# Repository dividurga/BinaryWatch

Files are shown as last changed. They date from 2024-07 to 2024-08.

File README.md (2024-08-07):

# Binary Watch Project

Welcome to the Binary Watch project! This repository contains all the files related to the design and development of binary watches using STM32 and ATMega328p microcontrollers. A blog post detailing this can be found at [https://divija.info/](https://divija.info/2024/08/04/binary-display-watch/)

## Project Overview

The Binary Watch is designed to display the time in a "binary but base 10 format". This means each digit of the time in base 10 format is displayed in binary on an LED matrix.

For example, 17:15 is expressed on the LED matrix as:

<pre>
  0   0
  1 0 1
0 1 0 0
1 1 1 1
</pre>

where 1 = LED ON and 0 = LED OFF

## Repository Structure

### watch_STM32
This directory contains the design and firmware for the STM32-based binary watch.

### watch_ATMega328p
This directory contains the design for the ATMega328p-based binary watch.

The firmware from the STM32 version can be modified to work for this hardware. Use the arduino versions of all the libraries and an RTC library for the DS3231 RTC chip

### Setting the Time

- When the code is uploaded for the first time, the RTC time is set to the compile time.
- The current time is displayed on the LED matrix in binary format.
- Everytime you reset or change the battery, the time is set to midnight. This choice is purely aesthetic; I would prefer that my watch always resets to a defined time instead of a random compile time everytime setup() runs. This is achieved by storing a flag in the EEPROM.

## Contributing

Contributions are welcome! I'm still struggling with getting the external oscillator to work with my setup. I think the issue is with my choice of extenal capacitors - they should be 15pF instead of 1pF. The RTC section of the code works perfectly fine on an external Nucleo board, so I think it is a hardware issue. If you have any suggestions or improvements, please open an issue or submit a pull request.

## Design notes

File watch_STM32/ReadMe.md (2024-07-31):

## Directory Structure

- **EEPROMReset**: The firmware uses a flag stored in the EEPROM to see if the RTC needs to be reset. This file resets the flag. Flash this code before using flashing watchFirmwareSTM32.ino .
- **watchFirmwareSTM32.ino**: The main firmware file for the binary watch.
- **watch_STM32 v26.f3z**: Fusion 360 archive file containing the design of the watch, including PCB and 3D models.
- **ReadMe.md**: The current readme file.

### Prerequisites

- [STM32CubeIDE](https://www.st.com/en/development-tools/stm32cubeide.html) or [Arduino IDE](https://www.arduino.cc/en/software) (with STM32 support)
- [Fusion 360](https://www.autodesk.com/products/fusion-360/overview) for 3D modeling and PCB design
- [Arduino IDE](https://www.arduino.cc/en/software) for flashing the firmware

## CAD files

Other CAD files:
watch_STM32/watch_STM32 v26.f3z

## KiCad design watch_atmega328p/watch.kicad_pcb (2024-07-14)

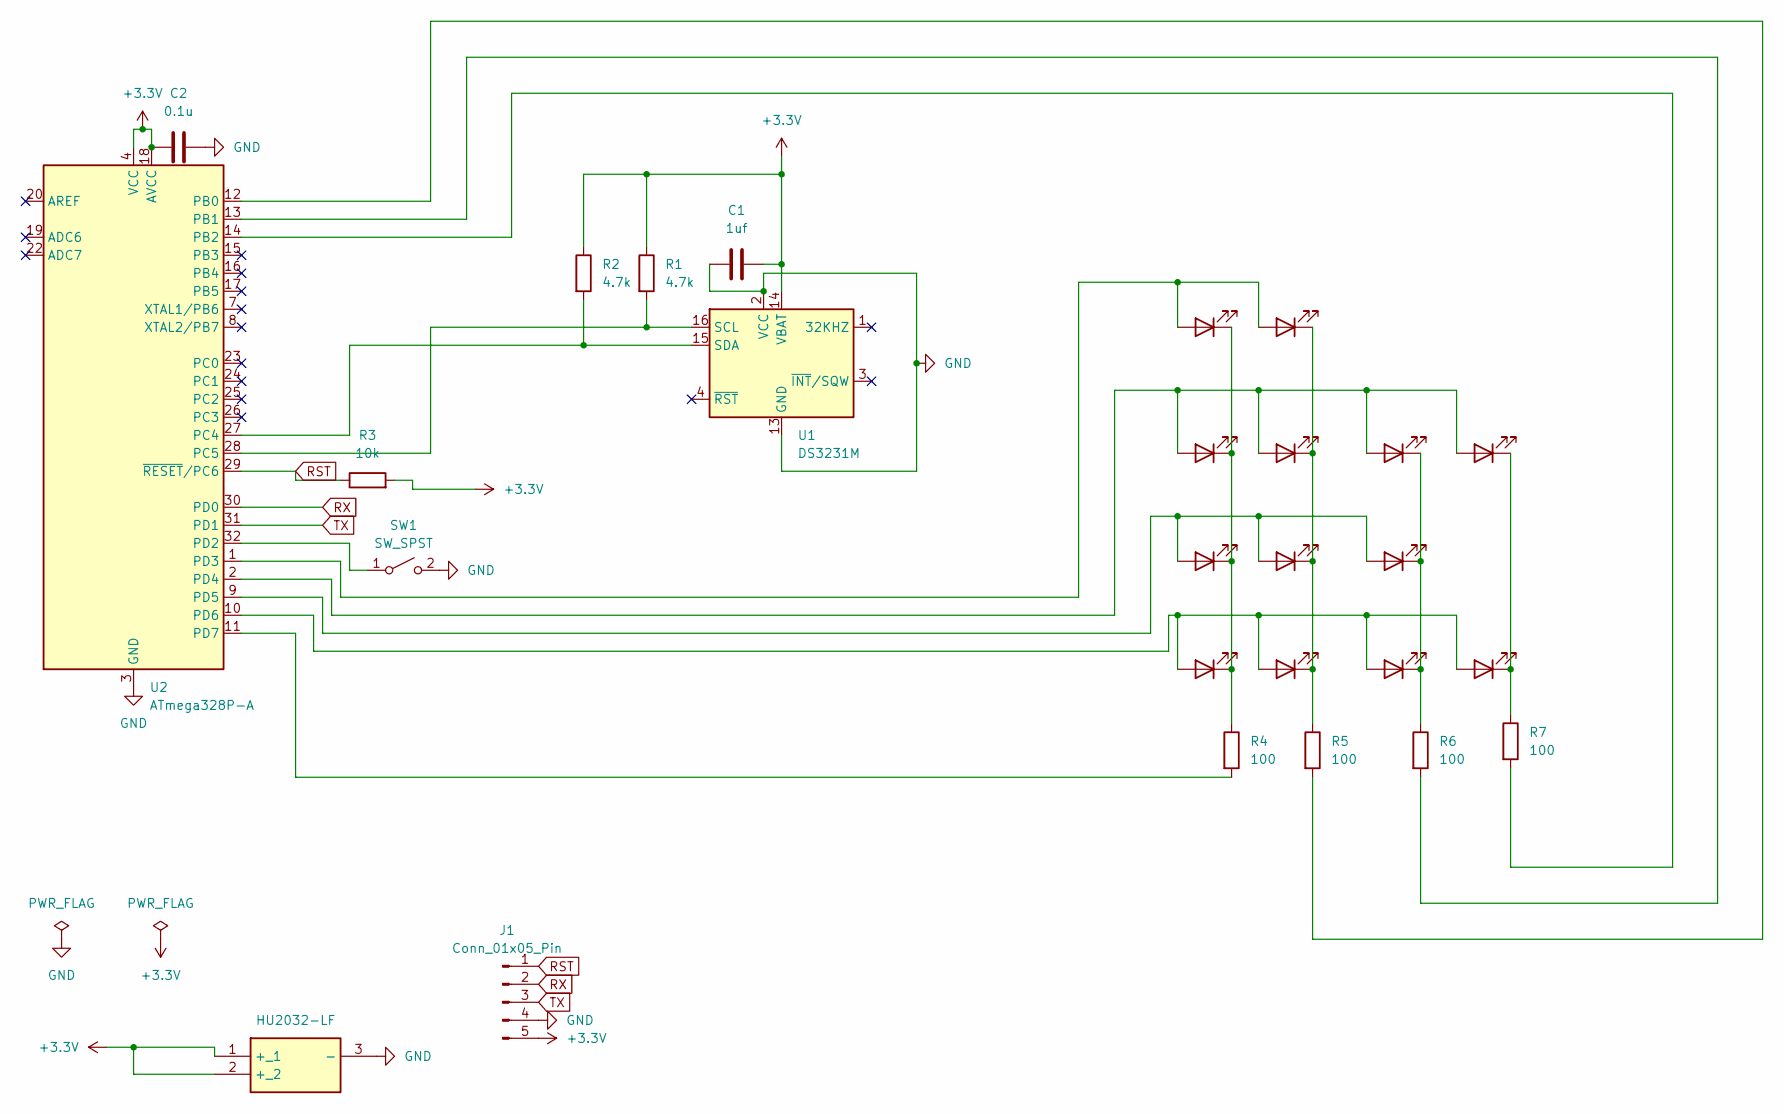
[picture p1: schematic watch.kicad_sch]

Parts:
C1: 1uf; C_1206_3216Metric
C2: 0.1u; C_1206_3216Metric
D1, D2, D3, D4, D5, D6, D7, D8, D9, D10, D11, D12, D13: LED; LED_1206_3216Metric
J1: Conn_01x05_Pin; TestPoint_Pad_2.0x2.0mm
R1, R2: 4.7k; R_1206_3216Metric
R3: 10k; R_1206_3216Metric
R4, R5, R6, R7: 100; R_1206_3216Metric
SW1: SW_SPST; SW_TL3342F160QG
U1: DS3231M; SOIC-16W_7.5x10.3mm_P1.27mm
U2: ATmega328P-A; TQFP-32_7x7mm_P0.8mm
U3: HU2032-LF; BAT_BAT-HLD-002-SMT-TR; Mouser Part Number 614-HU2032-LF

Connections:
+3.3V: C1.2, C2.1, J1.5, R1.1, R2.1, R3.2, U1.14 (VBAT), U2.4 (VCC), U2.6 (VCC), U2.18 (AVCC), U3.1 (+_1), U3.2 (+_2)
GND: C1.1, C2.2, J1.4, SW1.2 (B), U1.2 (VCC), U1.5 (GND), U1.6 (GND), U1.7 (GND), U1.8 (GND), U1.9 (GND), U1.10 (GND), U1.11 (GND), U1.12 (GND), U1.13 (GND), U2.3 (GND), U2.5 (GND), U2.21 (GND), U3.3 (-)
unnamed: D1.2 (A), D2.2 (A), U2.1 (PD3)
unnamed: D1.1 (K), D5.1 (K), D8.1 (K), D12.1 (K), R5.1
unnamed: D3.2 (A), D4.2 (A), D5.2 (A), D6.2 (A), U2.2 (PD4)
unnamed: D7.2 (A), D8.2 (A), D9.2 (A), U2.9 (PD5)
unnamed: D10.2 (A), D11.2 (A), D12.2 (A), D13.2 (A), U2.10 (PD6)
unnamed: D3.1 (K), D10.1 (K), R7.1
unnamed: D4.1 (K), D7.1 (K), D11.1 (K), R6.1
unnamed: D2.1 (K), D6.1 (K), D9.1 (K), D13.1 (K), R4.1
unnamed: SW1.1 (A), U2.32 (PD2)
unnamed: R1.2, U1.16 (SCL), U2.28 (PC5)
unnamed: R2.2, U1.15 (SDA), U2.27 (PC4)
unnamed: R5.2, U2.12 (PB0)
unnamed: R6.2, U2.13 (PB1)
unnamed: R7.2, U2.14 (PB2)
unnamed: R4.2, U2.11 (PD7)
RST: J1.1, R3.1, U2.29 (~RESET/PC6)
RX: J1.2, U2.30 (PD0)
TX: J1.3, U2.31 (PD1)

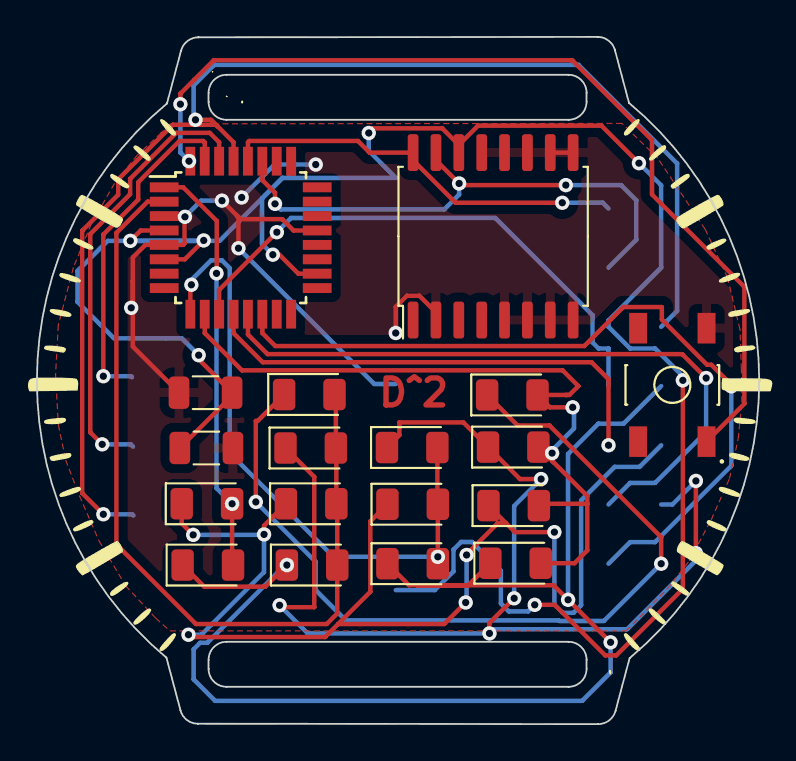
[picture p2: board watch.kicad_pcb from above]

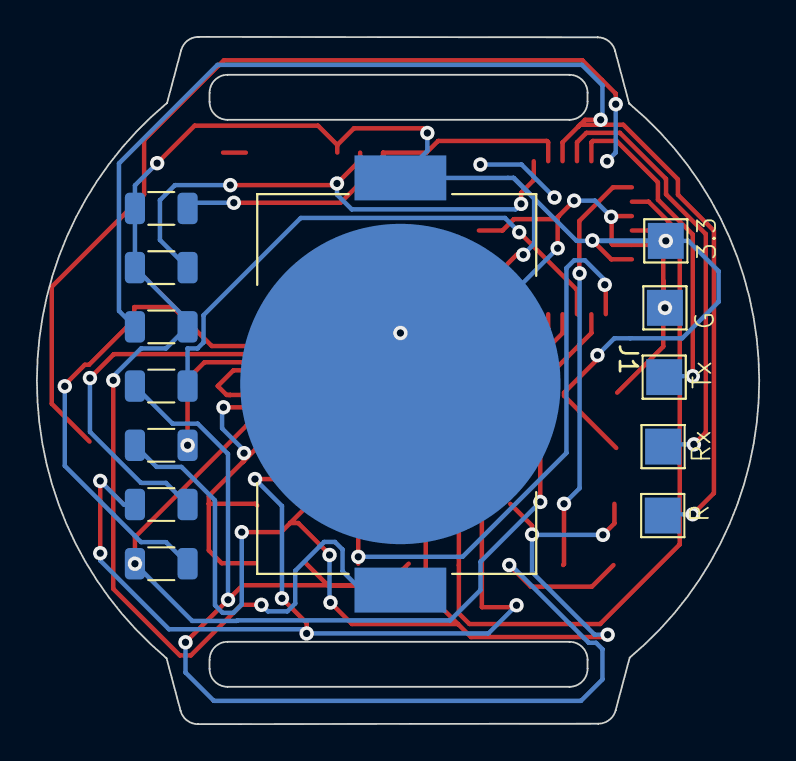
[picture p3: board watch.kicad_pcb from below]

Board: 2 copper layers, 40.1 x 38.2 mm, 27 parts (9 on the bottom side), 20 nets.

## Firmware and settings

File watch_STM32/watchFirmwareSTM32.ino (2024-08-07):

/*
This code uses the in-built RTC of the STM32G070KBT6, and then converts this data into a "binary but base 10 format". 
This means that each digit of the time in base 10 format is displayed in binary. 

For example, 17:45 is expressed on the LED matrix as: 
  0   0 
  1 1 1
0 1 0 0
1 1 0 1 

where 1 = LED ON and 0 = LED OFF

This code makes optimizations, like using the lowpower library to conserve battery life, and using the EEPROM
to store if the time has been reset already.

Created by Divija Durga, 31 July, 2024
*/


#include <STM32RTC.h>
#include "STM32LowPower.h"
#include <EEPROM.h>  // Include EEPROM library

bool awake = false;  // Flag to indicate if the device is awake
uint8_t hour;
uint8_t minutes;
int onTime = 3000;  // Time to keep the LED matrix on
unsigned long sleepTimer;  // Timer to track sleep time

// Get the RTC object
STM32RTC& rtc = STM32RTC::getInstance();

// Define pin constants for waking up and LED matrix columns/rows
const int pin = PA6;                             // Pin for waking up
const uint8_t col[4] = { PB2, PB1, PB0, PA7 };   // Columns of the LED matrix
const uint8_t row[4] = { PA8, PA9, PC6, PA10 };  // Rows of the LED matrix

const int eepromAddress = 0;               // EEPROM address to store the reset flag
void setup() {
  Serial.begin(9600);  // Start serial communication at 9600 baud rate
  
  // Initialize the column and row pins
  for (int i = 0; i < 4; i++) {
    pinMode(col[i], OUTPUT);
    pinMode(row[i], OUTPUT);
  }
  
  // Set pin as INPUT_PULLUP to avoid spurious wakeup
  pinMode(pin, INPUT_PULLUP);
  
  // Clear the LED matrix
  clearMatrix();
  
  // Configure low power mode
  LowPower.begin();

  // Select RTC clock source: LSI_CLOCK, LSE_CLOCK or HSE_CLOCK.
  // By default the LSI is selected as source.
  rtc.setClockSource(STM32RTC::LSE_CLOCK);
  rtc.begin();  // Initialize RTC in 24H format

  // Check if the RTC time has been set before
  if (EEPROM.read(eepromAddress) != 1) {
    // RTC time has not been set, set it to compile time
    const char compileTime[] = __TIME__;
    int hour, minute, second;
    sscanf(compileTime, "%d:%d:%d", &hour, &minute, &second);

    rtc.setHours(hour);
    rtc.setMinutes(minute);
    rtc.setSeconds(second);
    EEPROM.write(eepromAddress, 1);  // Write flag to EEPROM indicating that the time has been set

  } else {
    // RTC time has been set before, set it to 00:00
    rtc.setHours(0);
    rtc.setMinutes(0);
    rtc.setSeconds(0);
  }
  
  // Clear the LED matrix again
  clearMatrix();

  // Attach an interrupt to wake up the device and print time
  LowPower.attachInterruptWakeup(pin, printTime, RISING, SLEEP_MODE);
}

void loop() {
  // Check if the device is awake
  if (awake) {
    // Check if the LED display time is still valid
    if (millis() - sleepTimer < onTime) {
      // Set LED for hour tens position
      binaryColumn(0, hour / 10);
      // Set LED for hour ones position
      binaryColumn(1, hour % 10);
      // Set LED for minutes tens position
      binaryColumn(2, minutes / 10);
      // Set LED for minutes ones position
      binaryColumn(3, minutes % 10);
    } else {
      // Turn off the LED display
      awake = false;
    }
  }

  // Put the device to sleep if it is not awake
  if (!awake) {
    LowPower.sleep();
  }
}

// Print date and time
void printTime() {
  hour = rtc.getHours();
  minutes = rtc.getMinutes();
  sleepTimer = millis();  // Start the sleep countdown
  awake = true;  // Flag to start LED matrix
}

// Set a specific LED in the matrix
void setLED(uint8_t rowNum, uint8_t colNum) {
  digitalWrite(col[colNum], HIGH);  // Set column HIGH
  digitalWrite(row[rowNum], LOW);   // Set row LOW
}

// Clear the LED matrix
void clearMatrix() {
  // Set all columns to LOW and all rows to HIGH to clear the matrix
  for (int i = 0; i < 4; i++) {
    for (int j = 0; j < 4; j++) {
      digitalWrite(col[i], LOW);
      digitalWrite(row[j], HIGH);
    }
  }
}

// Display a binary number on a specific column of the LED matrix
void binaryColumn(uint8_t colPin, uint8_t num) {
  int numLEDs;
  // Determine number of LEDs in the column based on the column position
  if (colPin == 0) {
    numLEDs = 2;
  } else if (colPin == 1 || colPin == 3) {
    numLEDs = 4;
  } else if (colPin == 2) {
    numLEDs = 3;
  }

  // Set LEDs based on the binary representation of the number
  for (uint8_t i = 0; i < numLEDs; i++) {
    uint8_t bit = (num >> i) & 1;  // Get the bit at position i
    if (bit == 1) {
      setLED(i, colPin);  // Turn on the LED if the bit is 1
      delayMicroseconds(300); // Persistence of vision
      clearMatrix();  // Clear the matrix after each bit
    }
  }
}

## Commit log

2024-07-14 added files for atmega version
    [watch.kicad_pcb, watch.kicad_sch]
2024-07-31 Added fusion 360 files
    [watch_STM32 v26.f3z]
